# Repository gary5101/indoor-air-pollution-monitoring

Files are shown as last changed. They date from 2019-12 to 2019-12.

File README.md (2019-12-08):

Motivation
==========

Food production areas are prone to much air pollution as they will be using inflammable fuels,burning coal and other organic matter.
Despite this pollution, these areas should be kept clear of other air pollutants and gases.

Overview
========

In this project we monitor the air pollutants(Particulates,Volatile Organic Compounds,Carbon monoxide,Nitrogen dioxide,Ammonia,Methane,Propane etc) in food production areas.

The data which is collected is then sent to cloud for easy monitoring and analytics.

Here we basically collect the amount of pollutants and check the levels to assure the safety of the workers and the standards of the food.

Importance
==========

<span>Need of our Project</span>

**AQI**

The AQI is an index for reporting daily air quality. It tells you how clean or polluted your air is, and what associated health effects might be a concern for you. EPA calculates the AQI for five major air pollutants regulated by the Clean Air Act: ground-level ozone, particle pollution (also known as particulate matter), carbon monoxide, sulfur dioxide, and nitrogen dioxide. EPA has established national air quality standards to protect public health .
We use our collected data and make a AQI value and compare to the above standards to ensure a healthy environment.

<span>AQI</span> The higher the AQI value, the greater the level of air pollution and the greater the health concern.
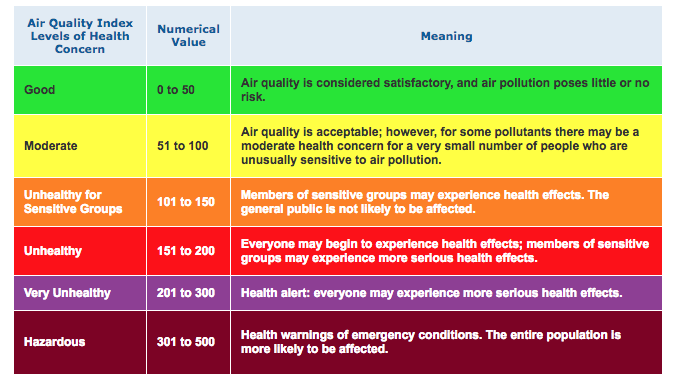
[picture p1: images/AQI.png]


Description
===========

<span>Goals</span> 

**Goals**

-   Measure the air quality index in the messes

-   To upload the air quality index to the cloud regularly to ensure the safety levels are not crossed.

-   To analyze the data collected and provide a solution if the safety levels are breached

<span>Implementation</span> 

**Steps**

-   Making the layout of the circuit

-   Connecting the sensors and controller according to the circuit

-   Writing of the code to test the sensors

-   Building of a datbase in a cloud to store the data collected

-   Update the code to connect the microcontroller to the cloud

-   Designing the final structure of the node

-   Deployment of the device

-   Analyzing the data stored in the cloud

<span>Deployment</span>

At the time of deployment of the, each node contains:-

1.  All the sensors with board(enclosed)

2.  jio-fi

3.  powerbank(power supply)

In the end 4 such node are deployed i.e 2 node in each mess

-   NBH mess

-   North mess

<span>List of Sensors and Controllers</span>

-   NodeMCU

-   Nova PM2.5 - PM10 - High Precision Air Particulate Matter Sensor

-   Digital Temperature and Humidity Sensor

-   Grove multichannel gas sensor

-   Grove - VOC and eCO2 Gas Sensor

Tools and Technologies
======================

NodeMCU
=======

<span>NodeMCU</span>

NodeMCU is an open source LUA based firmware developed for ESP8266 wifi chip.The ESP8266 is a low-cost Wi-Fi chip developed by Espressif Systems with TCP/IP protocol. NodeMCU Dev Kit has Arduino like Analog (i.e. A0) and Digital (D0-D8) pins on its board.It supports serial communication protocols i.e. UART, SPI, I2C etc.

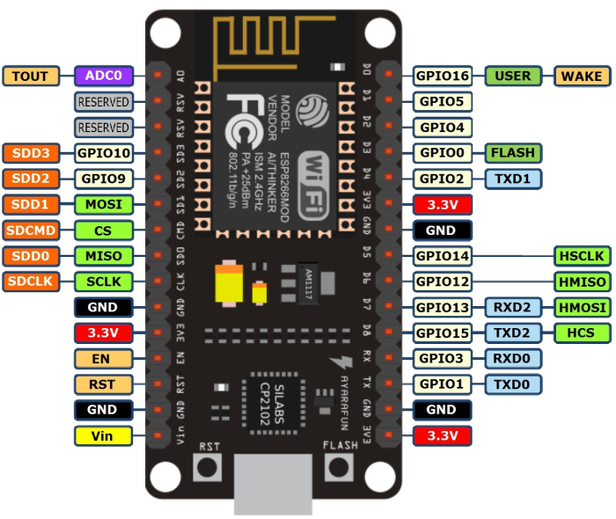
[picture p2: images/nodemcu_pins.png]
NodeMCU pin layout


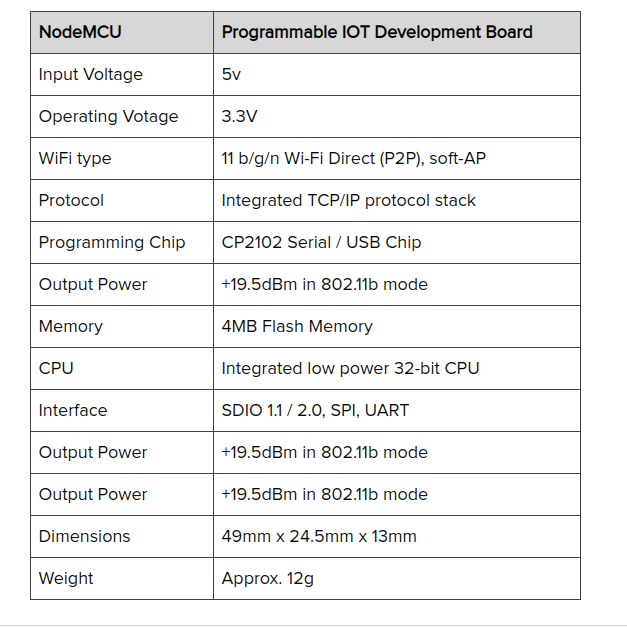
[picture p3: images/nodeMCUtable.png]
<span>NodeMCU Specifications</span> 

<span>NodeMCU vs esp32</span> ESP32 is more expensive than the ESP8266.Additionally, because it is more recent than the ESP8266, not all software has been developed to take the most out of the ESP32 functionalities, there is less support, and more bugs. But on the long run these issues will be fixed, and there will be space for both boards.

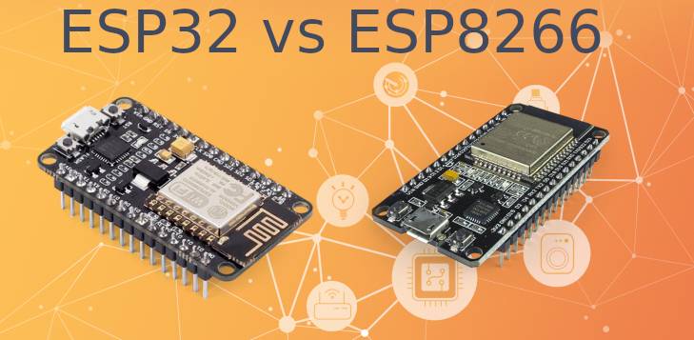
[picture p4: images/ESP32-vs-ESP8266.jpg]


Nova PM2.5 - PM10 (SDS011)
==========================

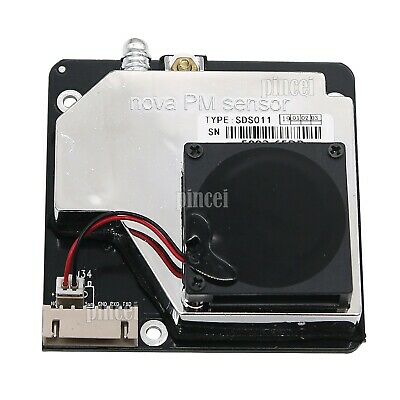
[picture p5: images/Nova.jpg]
<span>Nova PM2.5 - PM10 (SDS011)</span> The SDS011 using principle of laser scattering,can get the particle concentration between 0.3 to 10μm in the air. It gives direct digital output via serial protocol at 9600bps and also over 2 PWM channels. There is a built-in fan for stable and reliable operations. 

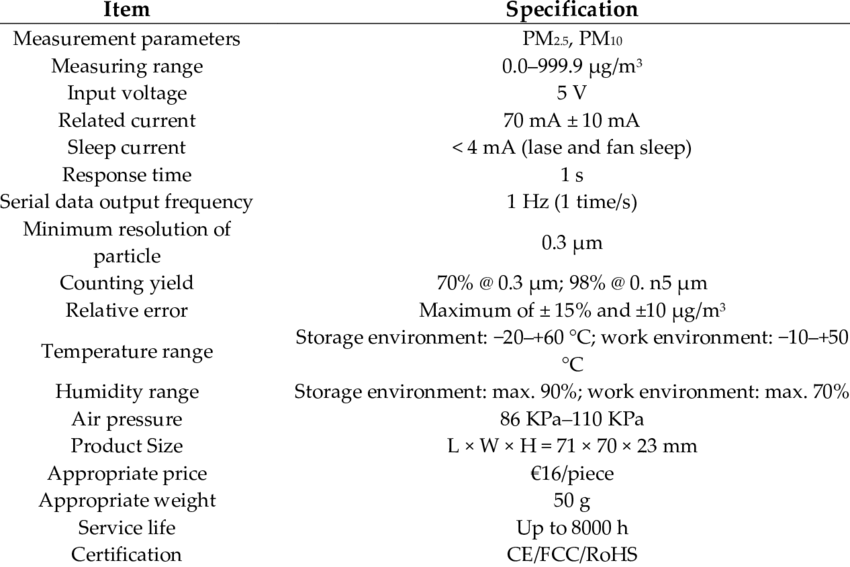
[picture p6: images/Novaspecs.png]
<span>Nova PM2.5 - PM10 (SDS011) Specifications</span> 

<span>Nova PM2.5 - PM10 (SDS011) Pin Layout</span>

-   Pin 1 - not connected

-   Pin 2 - PM2.5: 0-999μg/m³; PWM output

-   Pin 3 - 5V

-   Pin 4 - PM10: 0-999 μg/m³; PWM output

-   Pin 5 - GND

-   Pin 6 - RX UART (TTL) 3.3V

-   Pin 7 - TX UART (TTL) 3.3V

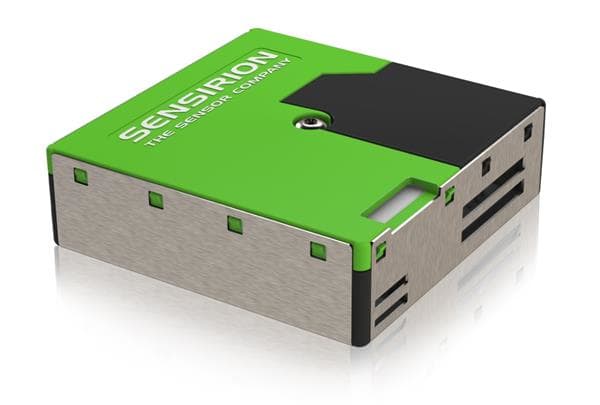
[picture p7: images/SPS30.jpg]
<span>SDS011 vs SPS30</span> 
SPS30 has sophisticated technology with high quality and long-lasting compounds which is used mostly for accurate measurements and which also makes it very expensive.For household environments SDS011 provides ease than SPS30.

DHT22 AM2302 Module
===================

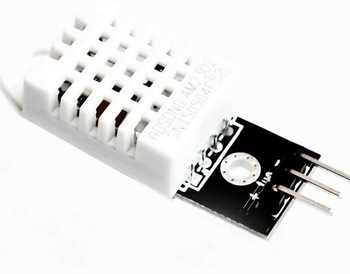
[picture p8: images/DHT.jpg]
<span>DHT22 AM2302 Module</span> It uses a capacitive humidity sensor and a thermistor to measure the surrounding air, and spits out a digital signal on the data pin (no analog input pins needed). Its fairly simple to use, but requires careful timing to grab data. The only real downside of this sensor is you can only get new data from it once every 2 seconds, so when using our library, sensor readings can be up to 2 seconds old. 

<span>DHT22 AM2302 Module Specifications</span>

-   Low cost

-   3 to 5V power and I/O

-   2.5mA max current use during conversion (while requesting data)

-   Good for 0-100

-   Good for -40 to 80$^circ$C temperature readings 0.5$^circ$C accuracy

-   No more than 0.5 Hz sampling rate (once every 2 seconds)

-   Body size 15.1mm x 25mm x 7.7mm

-   4 pins with 0.1" spacing

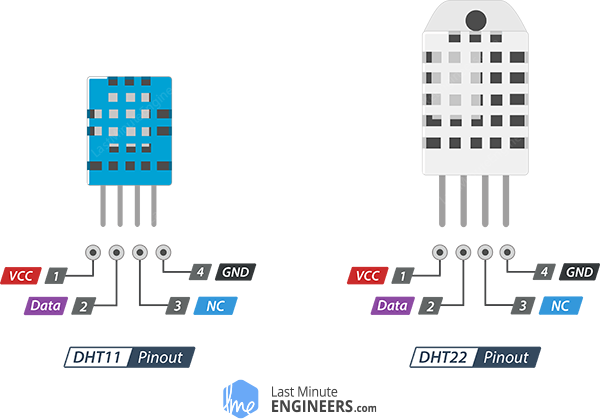
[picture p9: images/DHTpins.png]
<span>DHT22 AM2302 Pin Layout</span> 

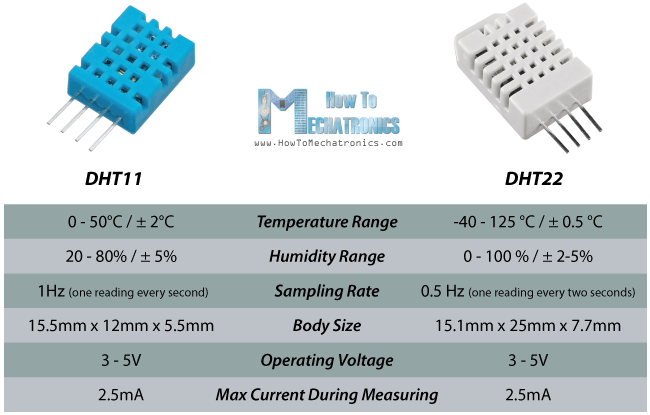
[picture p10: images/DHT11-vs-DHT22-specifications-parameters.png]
<span>DHT22 vs DHT11</span> The DHT22 is the more expensive version which obviously has better specifications. Its temperature measuring range is from -40 to +125 degrees Celsius with +-0.5 degrees accuracy, while the DHT11 temperature range is from 0 to 50 degrees Celsius with +-2 degrees accuracy. Also the DHT22 sensor has better humidity measuring range, from 0 to 100% with 2-5% accuracy, while the DHT11 humidity range is from 20 to 80% with 5% accuracy. 

Grove multichannel gas sensor
=============================

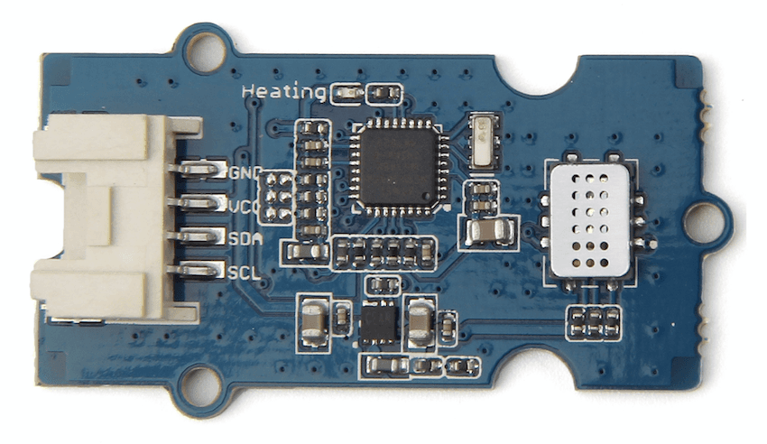
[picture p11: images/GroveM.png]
<span>Grove multichannel gas sensor</span> Grove Multichannel Gas sensor is a environment detecting sensor with a built in MiCS-6814 which can detect many unhealthful gases, and three gases can be measured simultaneously due to its multi channels, so it can help you to monitor the concentration which more than one gas. 

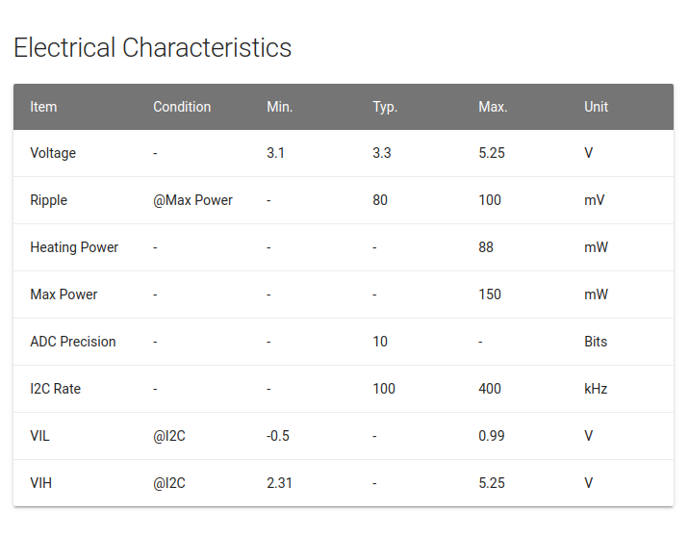
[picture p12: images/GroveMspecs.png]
<span>Grove multichannel gas sensor (MICS 6814) Characteristics</span> 

<span>Grove multichannel gas sensor (MICS 6814) Specifications</span> **Features**

-   Three fully independent sensing elements on one package

-   Built with ATmega168PA

-   I2C interface with programmable address

-   Heating power can be shut down for low power

-   Detectable gases

-   Carbon monoxide CO 1 to 1000ppm

-   Nitrogen dioxide NO2 0.05 to 10ppm

-   Ethanol C2H6OH 10 to 500ppm

-   Hydrogen H2 1 to 1000ppm

-   Ammonia NH3 1 to 500ppm

-   Methane CH4 >1000ppm

-   Propane C3H8 >1000ppm

-   Iso-butane C4H10 >1000ppm

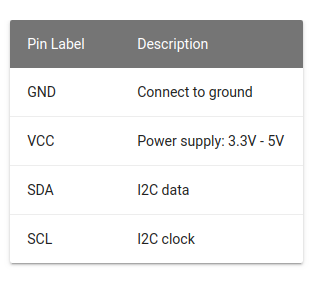
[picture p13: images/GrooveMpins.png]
<span>Grove multichannel gas sensor (MICS 6814) Pin Layout</span> 

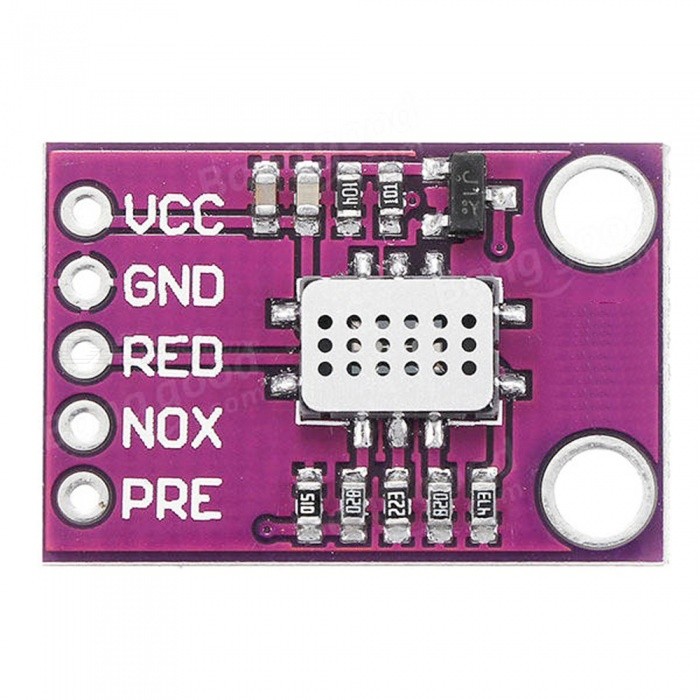
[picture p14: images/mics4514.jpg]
<span>MICS 6814 vs MICS 4514</span> 
MICS 4514 has CO/NO2 dual sensor whereas MICS 6814 has CO/NO2/NH3 triple sensor. The CO and NO2 measurements are taken by means of the MiCS-4514 MicroElectroMechanical Sensor (MEMS) [30]. This is a sensor typically used in automotive applications (e.g., to measure emissions from automobile exhausts). Hence, it is optimized for high concentration of gases,but in human environment where we don’t have such high concentrations, MICS 6814 works efficiently.

Grove - VOC and eCO2 Gas Sensor(SGP30)
======================================

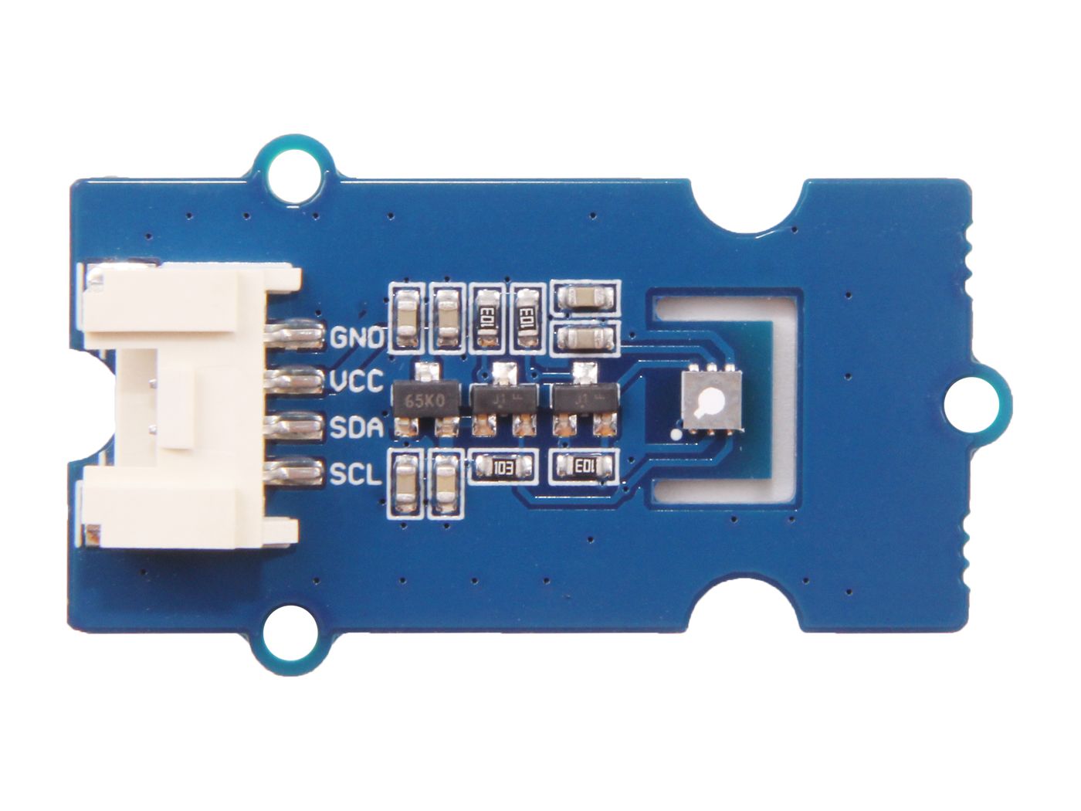
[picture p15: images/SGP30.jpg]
<span>Grove - VOC and eCO2 Gas Sensor(SGP30)</span> The Grove-VOC and eCO2 Gas Sensor(SGP30) is an air quality detection sensor. This grove module is based on SGP30, provided TVOC(Total Volatile Organic Compounds) and CO2eq output for this module. 

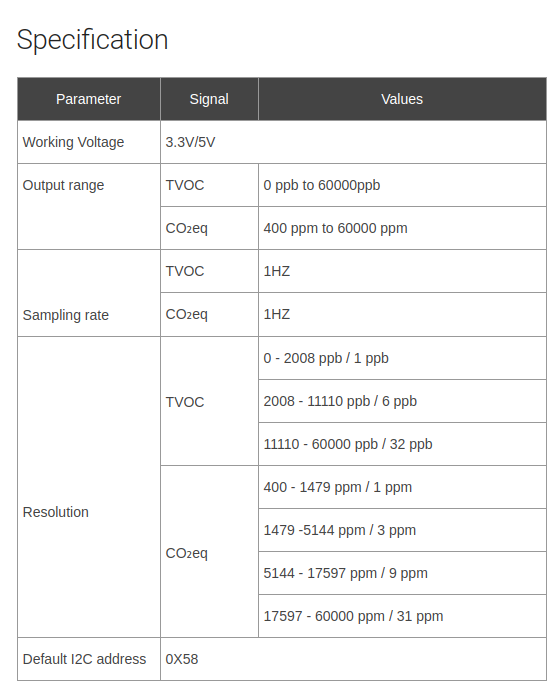
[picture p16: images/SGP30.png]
<span>Grove - VOC and eCO2 Gas Sensor(SGP30) Specifications</span> 

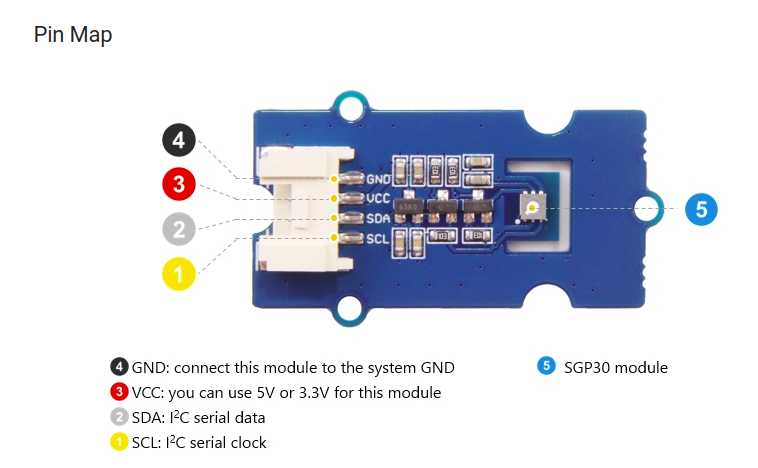
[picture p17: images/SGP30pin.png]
<span>SGP30 Pin Layout</span> 

<span>SGP30 vs CCS811</span> 

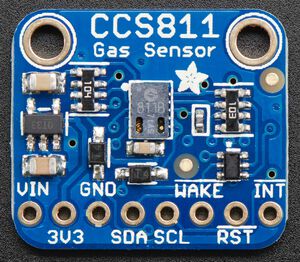
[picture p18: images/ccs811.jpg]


From a firmware perspective SGP30 is almost as easy as the CCS811. From the test data, SGP30 is way more sensitive than the CCS811. If you are in an environment where you need to know SGP30 is the one to pick. SGP30 is widely available though many channels.

Technology
==========

<span>Technology</span> **Connecting to Cloud**
The program connects to the Wi-Fi network using the provided password and SSID. It then proceeds to connect to the provided cloud/host server , and sends the provided URI to the host server.
Once the data has been successfully sent, the sketch waits for a reply from the server. The process is repeated until the ESP8266 is turned off.

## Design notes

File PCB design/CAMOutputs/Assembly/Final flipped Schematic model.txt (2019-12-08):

Partlist exported from C:/Users/VINAY KUMAR/Documents/EAGLE/projects/esw/Final flipped Schematic model.sch at 08-11-2019 11:04

Qty Value  Device                      Package Parts    Description POPULARITY VALUE 
2          PINHD-1X15                  1X15    JP1, JP2 PIN HEADER  4                
1          PINHD-1X3                   1X03    JP3      PIN HEADER  92               
1          PINHD-1X4                   1X04    JP4      PIN HEADER  91               
2   4P-2.0 GROVE-CONNECTOR-DIP(4P-2.0) HW4-2.0 J1, J2   320110033              4P-2.0

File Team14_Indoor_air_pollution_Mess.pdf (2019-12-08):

# Project Documentation

# Indoor Air Monitoring System Embedded Systems Workshop 2019

# Abhishek Reddy G Vinay Kumar T Sachin Kumar D

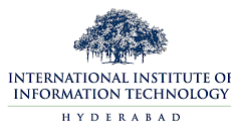
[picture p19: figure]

# International Institute of Information Technology Hyderabad

# Supervisor: Dr.Sachin Chaudhari Tanmai Mukku

# Contents

### 1 Developer Document

1.1 Introduction |
1.1.1 | Problem Definition |
1.1.2 | Purpose of System |
1.1.3 | Overview of System |
1.2 System Requirements |
1.2.1 | Hardware Requirements |
1.2.2 | Software Requirements |
1.3 System Requirements |
1.3.1 | Hardware Part |
1.3.2 | Software Part |
1.4 Stake Holders |
1.5 Design Details |
1.5.1 | Conceptual Flow |
1.5.2 | Entity Interaction |
1.6 Operational Requirements |
1.6.1 | System Needs |
1.6.2 | UI design |
1.6.3 | Analytical System |
1.7 Acknowledgement |
1.8 References |

### 2 User Document

2.1 Introduction |
2.1.1 | Objective |
2.1.2 | Scope |
2.2 Product Operational Requirements |
2.2.1 Operating Environment |
2.3 System Working Model |
2.3.1 | Base State |
2.3.2 | Working State |
2.4 Acknowledgement |

### 3 IOT Project Components

3.1 Hardware Specifications |
3.2 Communication |
3.3 Software specifications |
3.4 Data References |
3.5 Data Handling/Visualization |

# Indoor Air Quality Monitoring System

Abhishek Redddy G
Computer Science Engineering IIIT,Hyderbad,India 500032 abhishek.gangapuram@students.iiit.ac.in

Vinay Kumar T
Computer Science Engineering IIIT,Hyderbad,India 500032 vinay.kumar@students.iiit.ac.in

Sachin Kumar D
Computer Science Engineering IIIT,Hyderbad,India 500032 sachin.danisetty@students.iiit.ac.in

Dr.Sachin Chaudhari
Internet of Things
IIIT,Hyderbad,India 500032 sachin.c@iiit.ac.in

Tanmai Mukku
Computer Science Engineering IIIT,Hyderbad,India 500032 tanmai.mukku@students.iiit.ac.in

Abstract—Indoor air pollution due to household cooking is a hidden public health problem especially in developing countries. Cooking practices have an influence on the amount of pollution. Higher prevalence of respiratory infections is associated with cooking smoke especially among children. Most documented literature points toward a higher prevalence of respiratory symptoms, lung cancer and impaired lung functions with cooking smoke. Cleaner fuels seemingly cause less pollution though the literature is rare on kerosene. Identifying household air pollutants and their health implications helps us prepare for various healthrelated issues. However, the real challenge is adopting changes to reduce the health effects of household air pollution and designing innovative interventions to minimize the risk of further exposure. We present you a sophisticated model of air quality monitoring system which sense the presence of different of various air pollutants and send them to cloud for easy analysis.
Index Terms—Air Monitoring System,Kitchen,Air Pollution,Pollutants
I. INTRODUCTION

In the words of Rosalynn Carter, “There is nothing more important than a good, safe and secure home”. It is believed that a house is the most secure and healthy environment for any individual. However, the house can also be a source of various air pollutants that can have a significant adverse impact on health.
Indoor air pollution within households is one of the main contributors of mortality and disability globally. Emission due to household cooking fuels is found to be one of the main factors affecting indoor air pollution. In most parts of the developing world, traditional devices are used for cooking. The incomplete com bustion of these give rise to many pollutants including carbon monoxide, aldehydes, nitrogen oxides, polycyclic aromatic hydrocarbons, etc. . Indoor cooking is also a primary source of particle pollution, which is also called ‘particulate matter’ (PM). This consists of solid and liquid particles in the air . In a study on PM, it was found that 29-48% of source- wise attribution was from solid fuels . An Indian study revealed that 50-80% of the total suspended particulate emissions of cooking stoves using biomass and coal, were respirable being less than 2 µm in size. According to a Chinese study, PM levels during winter were significantly correlated with the usage of solid fuel. Incomplete combustion is influenced by poor ventilation and the poor quality of cooking devices used in lower-income countries . Improved cooking devices are associated with less pollution. Furthermore, factors such as higher education is associated with the usage of improved cooking devices than traditional ones . In return, negative respiratory effects are less when improved cooking devices are used .
A. Problem Definition
Monitor the Air Quality Standards in Kitchens.
Using the NodeMCU and air pollutants sensors like Particulate sensors, Humidity and Temperature sensor,Multi-channel gas sensors and VOC and CO2 sensors, collect the amount of various air pollutants and send them to ONEM2M server and IOT cloud for easy further analysis.
B. Purpose of System
Food production area are prone much air pollution as they will be using
- Inflammable fuels
- Burning coal
- Organic matter
Despite this pollution these areas should be kept clear of other air pollutants and gases. The air pollutants’s concentration should be monitored to ensure the safety of the workers and the quality of the food.
C. Overview of System
In this project we monitor the air pollutants and standards such as
•Particulates
•Volatile organic compounds
•Carbon dioxide
•Nitrogen dioxide
•Ammonia
•Carbon monoxide
•Temperature and Humidity
The data which is collected is then sent to the ONEM2M server and Thingspeak cloud for easy monitoring and analytic.

II. SYSTEM REQUIREMENTS

A. Hardware Requirements
•Should use a processing unit to collect data from different sensors.
•Sensors should be used to collect the following data. •Temperature and Humidity.
•Concentration of Particulates.
•Concentration of Volatile Organic Compounds in air. •Concentration of gases like CO2,NO,CO,NH3
•Use a portable WiFi router to connect to the Internet.
•Use a power bank to act as an uninterruptible power supply.
B. Software Requirements
•Processing unit should be capable of sending data using WiFi to a cloud software.
•Should use ONEM2M as a service layer and send data to ONEM2M servers.
•Should send data to IOT platform like Thingspeak for easy analytic.

III. SYSTEM SPECIFICATIONS

A. Hardware part
List of controllers,sensors and other devices:
- NodeMCU
We use NodeMCU as our central processing unit connecting air pollutants sensors
– NodeMCU is an open source LUA based firmware developed for ESP8266 wifi chip.
– The ESP8266 is a low-cost Wi-Fi chip developed by Espressif Systems with TCP/IP protocol.
– NodeMCU Dev Kit has Arduino like Analog (i.e. A0) and Digital (D0-D8) pins on its board.
– It supports serial communication protocols i.e. UART, SPI, I2C etc.
- Nova PM2.5-PM10 Particulate Sensor(SDS011)
We use Nova particulate sensor to sense particulates with size under 2.5nm and more than 10nm in diameter.
– The SDS011 using principle of laser scattering,can get the particle concentration between 0.3 to 10µm in the air.
– It gives direct digital output via serial protocol at 9600bps and also over 2 PWM channels.
– There is a built-in fan for stable and reliable operations.
- Digital Humidity and Temperature Sensor(DHT22)

– It uses a capacitive humidity sensor and a thermistor to measure the surrounding air, and spits out a digital signal on the data pin (no analog input pins needed). – Its fairly simple to use, but requires careful timing to grab data.


Fig. 1. NodeMCU specifications [1]


Fig. 2. Nova PM2.5-PM10 sensor specifications [2]

– The only real downside of this sensor is you can only get new data from it once every 2 seconds, so when using our library, sensor readings can be up to 2 seconds old.
– DHT22 specifications [3]:
∗ Low cost
∗ 3 to 5V power and I/O
∗ 2.5mA max current use during conversion (while requesting data)
∗ Good for 0-100
∗ Good for -40 to 80 ◦ C temperature readings 0.5
- C accuracy
∗ No more than 0.5 Hz sampling rate (once every 2 seconds)
∗ Body size 15.1mm x 25mm x 7.7mm
- Grove Multi-channel sensor(MiCS-6814)
– Grove Multi-channel Gas sensor is a environment detecting sensor with a built in MiCS-6814 which can detect many unhealthful gases, and three gases can be measured simultaneously due to its multi channels,


Fig. 3. SGP-30 specifications [5]

so it can help you to monitor the concentration which more than one gas.
– Multi-channel gas sensor specifications [4]:

∗ Three fully independent sensing elements on one package
∗ Built with ATmega168PA
∗ I2C interface with programmable address
∗ Heating power can be shut down for low power ∗ Detectable gases
∗ Carbon monoxide CO 1 to 1000ppm
∗ Nitrogen dioxide NO2 0.05 to 10ppm
∗ Ethanol C2H6OH 10 to 500ppm
∗ Hydrogen H2 1 to 1000ppm
∗ Ammonia NH3 1 to 500ppm
∗ Methane CH4 ¿1000ppm
∗ Propane C3H8 ¿1000ppm
∗ Iso-butane C4H10 ¿1000ppm
- Grove VOC and CO2 Gas sensor(SGP-30)
– The Grove-VOC and eCO2 Gas Sensor(SGP30) is an air quality detection sensor.
– This grove module is based on SGP30, provided TVOC(Total Volatile Organic Compounds) and CO2eq output for this module.
- JioFi(JMR1040)
– We use JioFi to get internet access to post the data obtained from sensors in an ONEM2M server and IOT cloud to store them and for easy further analysis
- Zinq power bank
– We use a power bank to provide an uninterruptible power service for the whole device.

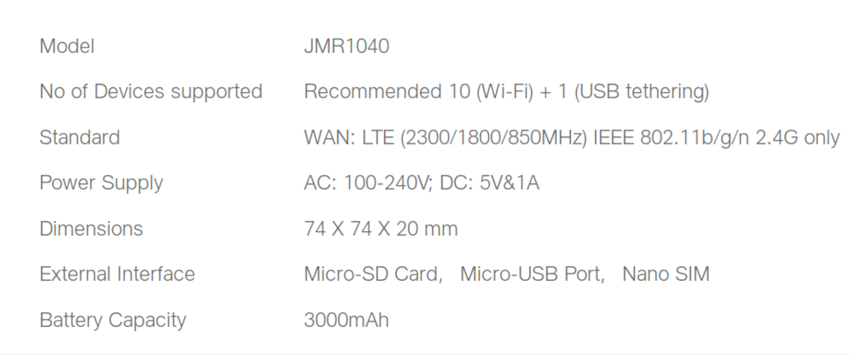
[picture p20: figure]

Fig. 4. JioFi specifications [6]

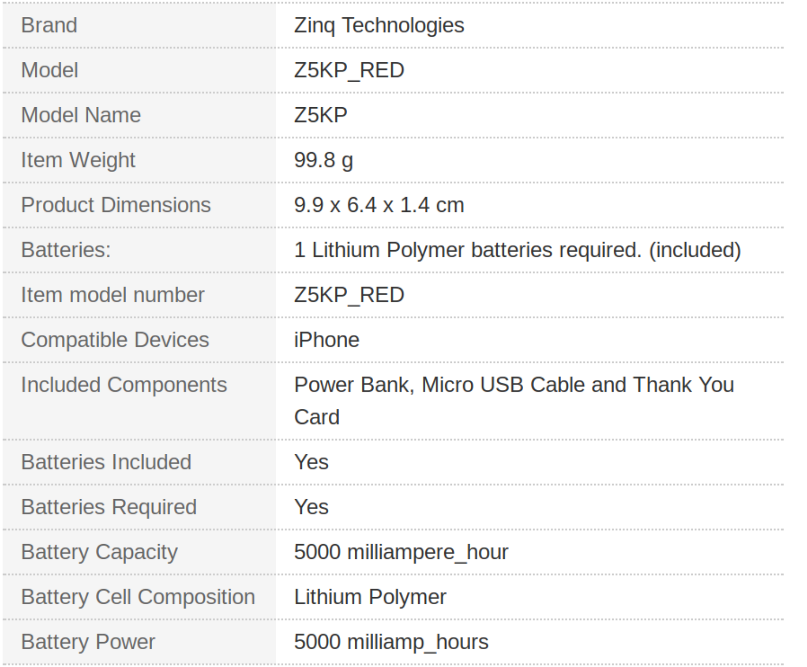
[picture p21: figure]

Fig. 5. Zinq power bank specifications [7]

– Ultra small and powerful: Smallest size for its capacity of 5000 mAh is very portable and easy to carry
– Input-output versatility: The power bank has Single input charging options of micro USB and has dual output ports with 2.0A fast charging
– 6-level protection: Built using the highest quality Lipolymer battery and protection from short circuits, current and voltage overloads overheating and wrong insertion
– Led indicator: A led indicators to find the status of charge ensuring you exactly know so that you don’t run into surprises
– Compatibility: Charge your iPhone, all Android devices, tablets, cameras and iPod, headphones
B. Software part
1) Arduino: We use Arduino IDE [8] for flashing the code in NodeMCU.Code is mentioned in the github repository given at last.
Arduino is an open-source physical computing platform based on a simple I/O board and a development environment that implements the Processing/Wiring language. Arduino can be used to develop stand-alone interactive objects or can be connected to software on your computer (e.g. Flash, Processing and MaxMSP). The boards can be assembled by hand or purchased preassembled; the open-source IDE can be downloaded for free at https://arduino.cc
2) ONEM2M: We added ONEM2M [9] service layer to our model to make it easy for machine to machine communication and security. We use ONEM2M API to send data to ONEM2M server.
The purpose and goal of oneM2M is to develop technical specifications which address the need for a common M2M Service Layer that can be readily embedded within various hardware and software, and relied upon to connect the myriad of devices in the field with M2M application servers worldwide. A critical objective of oneM2M is to attract and actively involve organizations from M2M-related business domains such as: telematics and intelligent transportation, healthcare, utilities, industrial automation, smart homes, etc.
3) Thingspeak: We also use Thingspeak [10] for IOT cloud to store data and do further analytic with MATLAB(integrated with Thingspeak).
our MATLAB functions used to analyze the air quality data collected by ThingSpeak. The MATLAB code helps preprocess the sensor data, provides functions to classify the data, and provides functions for visualizing the processed air quality data. The MATLAB visualizations are added to a ThingSpeak channel dashboard so you can see the current air quality near you. The MATLAB analysis code calculates the AQI using the definitions from the United States Environmental Protection Agency (EPA).
4) Dashboard: We built a data analysis dashboard on ThingSpeak using our available data and MATLAB. This project it makes it easy to explore IoT data analysis using MATLAB to preprocess and visualize data without having IoT hardware.

IV. STAKE HOLDERS

This device affects all the people working in mess or kitchens. It also affects the food quality.

V. DESIGN DETAILS
A. Conceptual Flow
The working of the device go as follows
- Firstly the processing unit,NodeMCU take power from the power bank and run the code flashed into it.
- NodeMCU, using its esp8266 WiFi module connects to the JioFi through the given SSID and password.
- Now NodeMCU collects data from each sensor and store them in variables.The NodeMCU collects data every 30 seconds.
- The data stored in variables is sent to different Thingspeak channels by using thingspeak API in Arduino IDE.
- For every 15 minutes, The NodeMCU post recent data to ONEM2M server by a certain CSE IP ,here it is onem2m.iiit.ac.in with port 80.
B. Entity Interaction
We have entities interacting in many different ways.
- NodeMCU - SDS011
This interaction uses UART communication.Rx pin of NodeMCU is connected to Tx pin of SDS011 and Tx pin of NodeMCU is connected to Rx pin of SDS011.

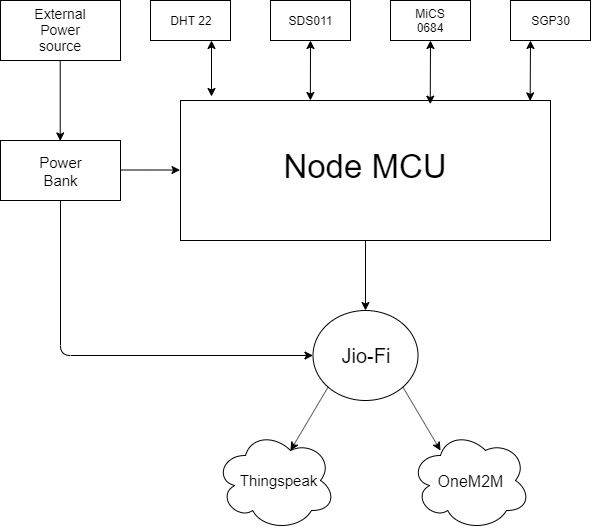
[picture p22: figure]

Fig. 6. Block diagram representation of the flow

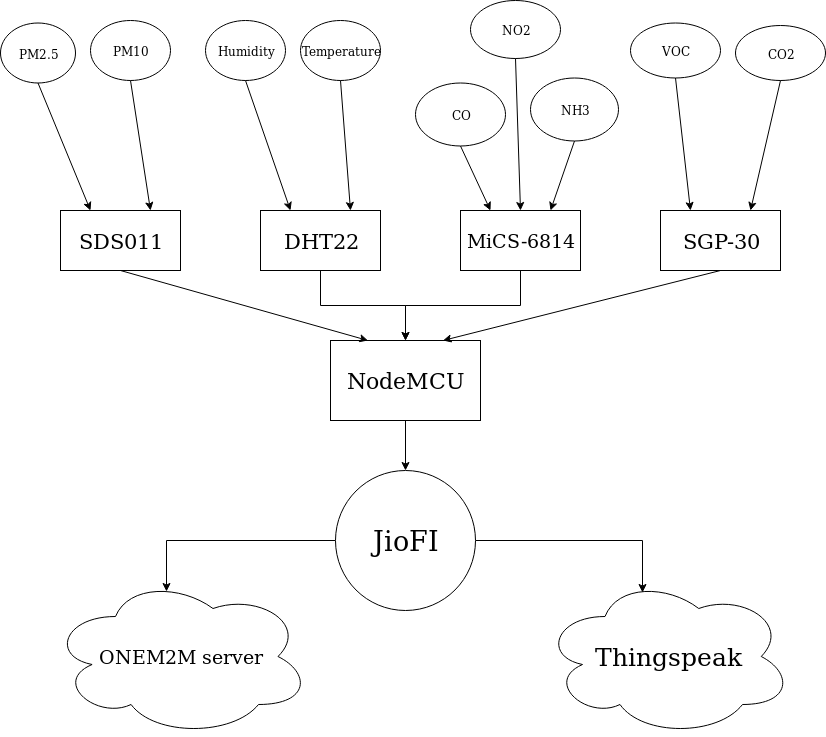
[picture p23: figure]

Fig. 7. Entities Interacting

- NodeMCU - DHT22
This interaction uses GPIO communication.D3 pin of NodeMCU is connected to DHT22.
- NodeMCU - MiCS-6814
This interaction uses I2C communication.D0 and D1 pins of NodeMCU are connected to SCK and SDA pins of Mics-6814.
- NodeMCU - SGP-30
This interaction uses I2C communication.D0 and D1 pins of NodeMCU are connected to SCK and SDA pins of SGP-30.
- NodeMCU - JioFi
This interaction uses WiFi communication.NodeMCU uses esp 8266 module to communicate to JioFi through WiFi.
- JioFi - ONEM2M or Thingspeak
Here the data is sent through post requests to both the servers and is stored there.

VI. OPERATIONAL REQUIREMENTS

A. System Needs
- Although power bank serves as the uninterruptible power source for both NodeMCU and JioFi,Power bank should be connected to a power source like a power socket all the time even when power bank is fully charged.
- The device should be hanged in open space in kitchen.It should be at a suitable height to get affected by pollutants.
- Since we need internet to post data to cloud, we need of consistent network signal for JioFi in the kitchen.
B. UI design
The device is cleanly,compactly enclosed in 3D-enclosure with two sides with grid walls to let free passage of air.
We can check the working condition by the led lights provided by JioFi to verify whether NodeMCU is connected to it or not. The power source can be verified by checking the led lights on power bank.
C. Analytical System
- ThingSpeak support functions let you use desktop MAT-LAB to analyze and visualize data stored on ThingSpeak.com or on private installations of ThingSpeak. With the MATLAB engine built into ThingSpeak, you can perform calibrations, develop analytics, and transform your IoT data.
Operationalize your analytics using the Time Control and React apps. With the Time Control app, you can schedule a computation to run once a day, once an hour, or as quickly as once every 5 minutes. The React App is used for condition monitoring. You can monitor the data coming in from your devices and set up an alert when the data indicates something may need attention.
- The data in ONEM2M server is stored in containers with time stamps,So, We know the date and time when the air pollutant levels are breached.

ACKNOWLEDGMENT
The work described in this project was conducted within IIIT Hyderabad and also funded by IIIT Hyderabad under Embedded Systems Workshop 2019.We sincerely thank Dr.Sachin Chaudhari and Tanmai Mukku for their support and guidance through the whole project.

REFERENCES

[1] https://veerobot.com/store/CB-MCU-IOTB-12
[2] https://cdn-reichelt.de/documents/datenblatt/X200/SDS011-DATASHEET.pdf
[3] https://www.adafruit.com/product/385
[4] http://wiki.seeedstudio.com/Grove-Multichannel Gas Sensor/
[5] http://wiki.seeedstudio.com/Grove-VOC and eCO2 Gas Sensor-SGP30/
[6] https://www.jio.com/shop/en-in/router-jmr1040-white/p/491193523
[7] https://www.amazon.in/Zinq-Technologies-Z10KI-10000mAH-Lithium/dp/B07MHCFRW5
[8] https://www.arduino.cc/en/main/software
[9] http://www.onem2m.org/about-onem2m/why-onem2m
[10] https://thingspeak.com/

# User Document

Abstract—We present you a sophisticated model of air quality monitoring system which sense the presence of different of various air pollutants and send them to cloud for easy analysis. Index Terms—Air Monitoring System,Kitchen,Air Pollution,Pollutants

I. INTRODUCTION

Indoor air pollution within households is one of the main contributors of mortality and disability globally. Emission due to household cooking fuels is found to be one of the main factors affecting indoor air pollution. In most parts of the developing world, traditional devices are used for cooking. The incomplete com bustion of these give rise to many pollutants including carbon monoxide, aldehydes, nitrogen oxides, polycyclic aromatic hydrocarbons, etc. . Indoor cooking is also a primary source of particle pollution, which is also called ‘particulate matter’ (PM). This consists of solid and liquid particles in the air . In a study on PM, it was found that 29-48% of source- wise attribution was from solid fuels

A. Objective
Monitor the Air Quality Standards in Kitchens.
With this device we should monitor the air pollutants and standards such as
•Particulates
•Volatile organic compounds
•Carbon dioxide
•Nitrogen dioxide
•Ammonia
•Carbon monoxide
•Temperature and Humidity
The data which is collected is then sent to the ONEM2M server and Thingspeak cloud for easy monitoring and analytic.
B. Scope
Food production area are prone much air pollution as they will be using
- Inflammable fuels
- Burning coal
- Organic matter
Despite this pollution these areas should be kept clear of other air pollutants and gases. The air pollutants’s concentration should be monitored to ensure the safety of the workers and the quality of the food.

II. PRODUCT OPERATIONAL REQUIREMENTS

A. Operating Environment
- This device is focused on but not constrained to kitchens and other food production areas.
- The device must be kept in an open space to let be affected by air pollutants.
- The device should be hanged at an appropriate height to the wall.
- The device should not get into contact with any liquid.
- The device shouldn’t kept directly above stove or below an exhaust fan.
- The device should be connected to a 220V socket.
- The device should have proper network signal to post data to cloud.
- The JioFi data card should have an active internet package to get access to internet.

III. SYSTEM WORKING MODEL
A. Base State
The first prototype is designed for testing and calibration with no physical enclosure.
It was designed on a breadboard.Then it was upgraded to a perforated circuit board.
It doesn’t include JioFi and power bank.
It has a power socket as it’s power source,since it is not an uninterruptible power source,the device is not a steady state device.
It was only integrated with Thingspeak.
Testing and Calibrating was done in a lab for a week and proper adjustments were made.
B. Working State
The working model is an advanced model of Base state. It was enclosed in a physical enclosure with some walls replaced by grills to have free passage of air.
The working state include JioFi and power bank which were absent in the Base state.
The working system has an uninterruptible power source unlike Base state.
The working state is designed on Printed Circuit Board which improve compactness to a great extent.
It is integrated with both Thingspeak and ONEM2M.The data can be accessed by ONEM2M dashboard and Thingspeak dashboard.It is even accessible in mobile through various mobile applications like Thingsview etc.

ACKNOWLEDGMENT
The work described in this project was conducted within IIIT Hyderabad and also funded by IIIT Hyderabad under Embedded Systems Workshop 2019.We sincerely thank Dr.Sachin Chaudhari and Tanmai Mukku for their support and guidance through the whole project.We also like to thank the Embedded Systems Workshop Professors for their guidance in various aspects and fields.

# 3 IOT Project Components

## 3.1 Hardware Specifications

- NodeMCU
NodeMCU is an open source LUA based firmware developed for ESP8266 wifi chip.The ESP8266 is a low-cost Wi-Fi chip developed by Espressif Systems with TCP/IP protocol. NodeMCU Dev Kit has Arduino like Analog (i.e. A0) and Digital (D0-D8) pins on its board.It supports serial communication protocols i.e. UART, SPI, I2C etc
- SDS011
The SDS011 using principle of laser scattering,can get the particle concentration between 0.3 to 10ˆIijm in the air. It gives direct digital output via serial protocol at 9600bps and also over 2 PWM channels. There is a built-in fan for stable and reliable operations
- DHT22
It uses a capacitive humidity sensor and a thermistor to measure the surrounding air, and spits out a digital signal on the data pin (no analog input pins needed). Its fairly simple to use, but requires careful timing to grab data. The only real downside of this sensor is you can only get new data from it once every 2 seconds, so when using our library, sensor readings can be up to 2 seconds old.
- MiCS-6814 Grove Multichannel Gas sensor is a environment detecting sensor with a built in MiCS-6814 which can detect many unhealthful gases, and three gases can be measured simultaneously due to its multi channels, so it can help you to monitor the concentration which more than one gas.
- SGP-30
The Grove-VOC and eCO2 Gas Sensor(SGP30) is an air quality detection sensor. This grove module is based on SGP30, provided TVOC(Total Volatile Organic Compounds) and CO2eq output for this module.

## 3.2 Communication

OneM2M is used for communication between the Node and Server. It has the following uses:

- Security and privacy aspects(authentication, encryption, integrity verification).
- Identification and naming of devices(for differentiating different devices).
- Data aggregation, buffering in case of missing connectivity and synchronisation upon connectivity re-establishment
- Group management and application and data discovery functions

Other forms of communications like UART and I2C are also used for the interacting components but are not used in the communication between the server and the node.

## 3.3 Software specifications

- Arduino IDE is used to program the microcontroller.
- Eagle Cad is used to design the printed circuit board.
- Fusion 360 is used to design the 3D printed box.
- Microsoft Excel is used to draw graphs for the collected data and for analysis.
- EasyEDA is used to draw the schematic representation of the circuit in the node.

## 3.4 Data References

Thingspeak

- https://thingspeak.com/channels/864652
- https://thingspeak.com/channels/864651
- https://thingspeak.com/channels/864650
- https://thingspeak.com/channels/864649
- https://thingspeak.com/channels/906528
- https://thingspeak.com/channels/907653
- https://thingspeak.com/channels/907654
- https://thingspeak.com/channels/907655

Github
https://github.com/SachinKumar105/Embedded-Systems-Workshop
OneM2M
http://onem2m.iiit.ac.in/webpage/welcome/index.html?context=/~&cseId=in-cse

## 3.5 Data Handling/Visualization

The data from the server is pulled by web-scraping. The data is also sent to Thingspeak server from where the data can be retrieved in an .xlsx format. The data from both are converted to the excel form and are further filtered and sorted according to date and time to provide better view of the results. These results are then represented as graphs.For Each of the sensors the average is taken for each day and for a particular day where the values are closest to these averages , the values are taken for each hour to see the change in the concentration of the gases across different times of the day. The obtained graphs for various sensors are as follows:

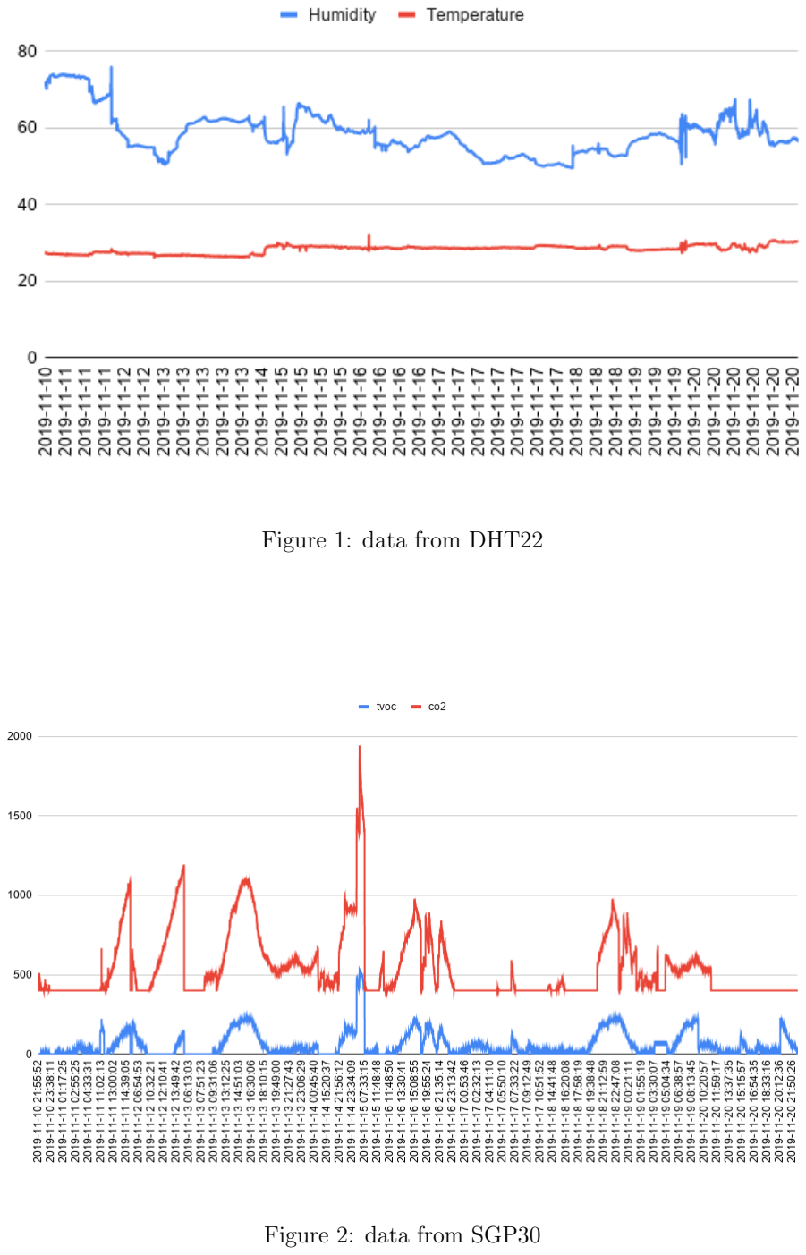
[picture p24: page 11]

Figure 1: data from DHT22

Figure 2: data from SGP30

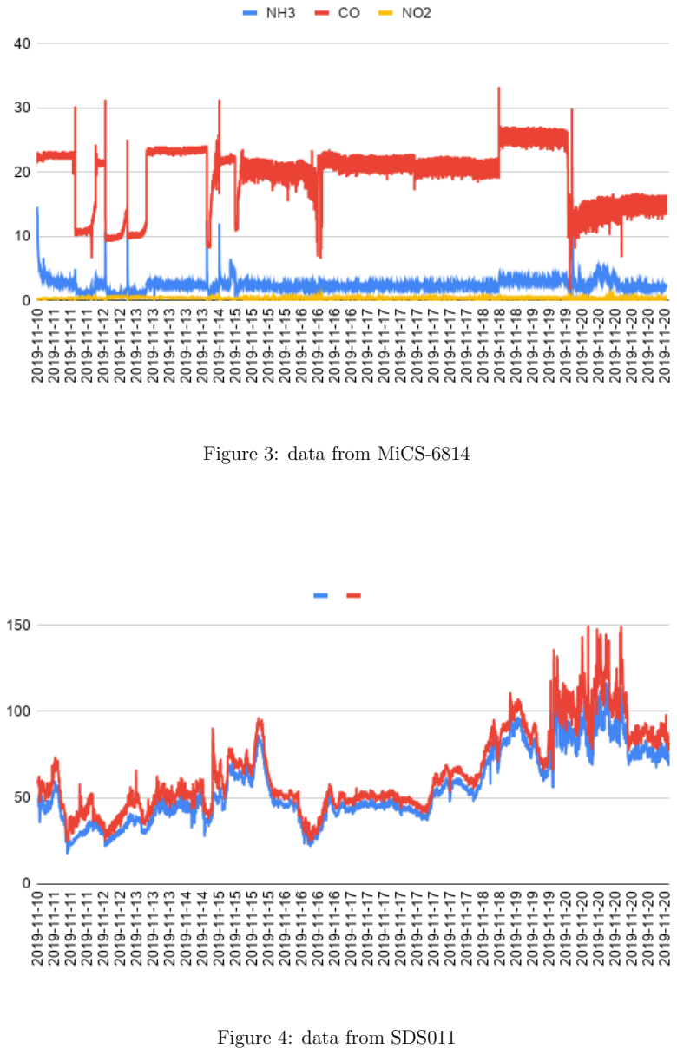
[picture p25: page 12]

Figure 3: data from MiCS-6814

Figure 4: data from SDS011

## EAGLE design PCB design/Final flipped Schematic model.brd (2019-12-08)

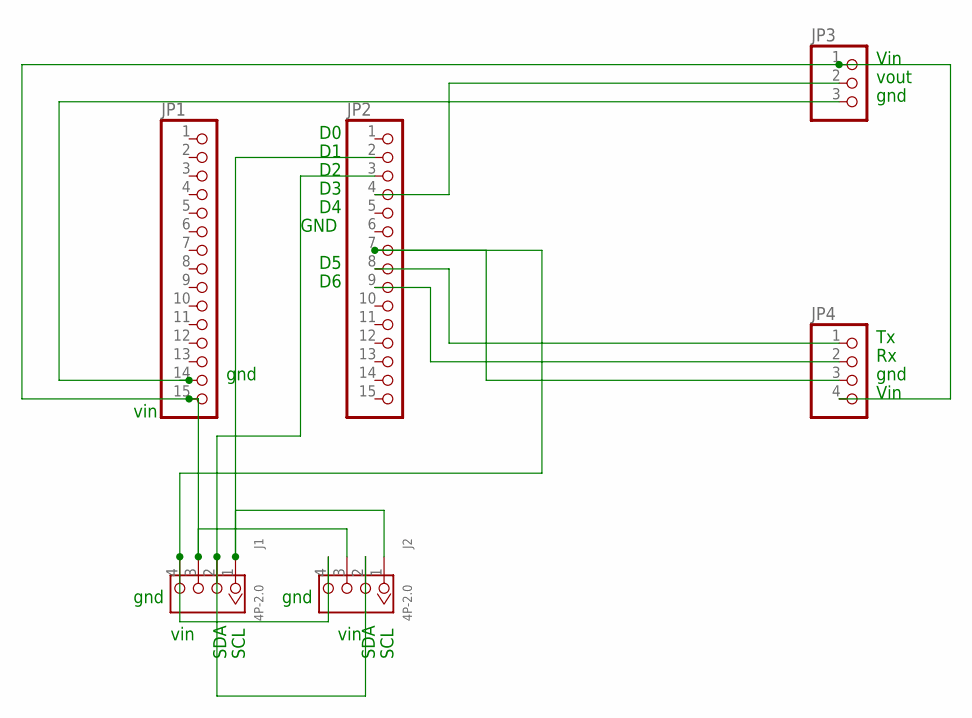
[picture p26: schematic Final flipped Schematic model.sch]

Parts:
J1, J2: 4P-2.0; HW4-2.0
JP1, JP2: PINHD-1X15; 1X15
JP3: PINHD-1X3; 1X03
JP4: PINHD-1X4; 1X04

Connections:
unnamed: JP2.8, JP4.1
unnamed: JP2.9, JP4.2
unnamed: JP2.4, JP3.2
unnamed: J1.1, J2.1, JP2.2
unnamed: J1.4, J2.4, JP2.7, JP4.3
unnamed: J1.2, J2.2, JP2.3
unnamed: J1.3, J2.3, JP1.15, JP3.1, JP4.4
unnamed: JP1.14, JP3.3

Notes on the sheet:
Vin
gnd
vout
GND
vin
SDA
SCL

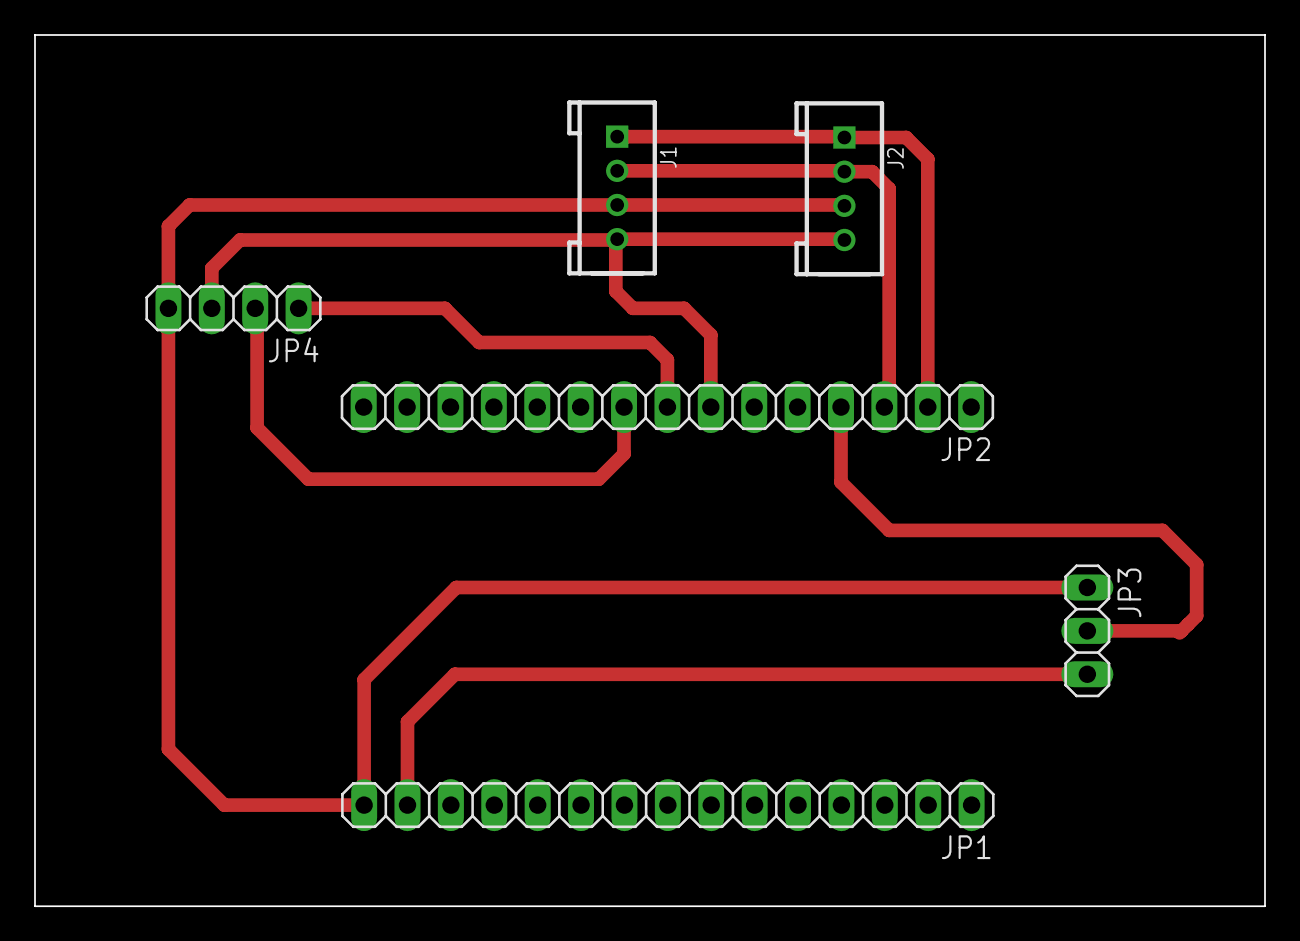
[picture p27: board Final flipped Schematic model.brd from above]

Board: 2 copper layers, 72.0 x 51.0 mm, 6 parts (0 on the bottom side), 8 nets.

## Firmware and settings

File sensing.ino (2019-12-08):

#include <JSONVar.h>
#include <Arduino_JSON.h>
#include <JSON.h>
#include <Wire.h>
#include "Adafruit_SGP30.h"
#include "MutichannelGasSensor.h"
#include <ESP8266WiFi.h>
#include <SoftwareSerial.h>
#include "SdsDustSensor.h"
#include "ThingSpeak.h"
#include <Arduino.h>
#include "sensirion_common.h"

#include <Adafruit_Sensor.h>
#include "DHT.h"
// Use this file to store all of the private credentials
// and connection details

#define SECRET_CH_ID1 864649      // replace 0000000 with your channel number
#define SECRET_WRITE_APIKEY1 "D6WO0I37GORJEIV9"   // replace XYZ with your channel write API Key

#define SECRET_CH_ID2 864650      // replace 0000000 with your channel number
#define SECRET_WRITE_APIKEY2 "DDEGP9X1V4WEGEFH"   // replace XYZ with your channel write API Key

#define SECRET_CH_ID3 864651      // replace 0000000 with your channel number
#define SECRET_WRITE_APIKEY3 "MC5M1BZI4U9422XF"   // replace XYZ with your channel write API Key

#define SECRET_CH_ID4 864652      // replace 0000000 with your channel number
#define SECRET_WRITE_APIKEY4 "1T9T3FK7NR422DJP"   // replace XYZ with your channel write API Key

//#define SECRET_CH_ID1 906528      // replace 0000000 with your channel number
//#define SECRET_WRITE_APIKEY1 "LL4J2EL6WCIW3SKD"   // replace XYZ with your channel write API Key
//
//#define SECRET_CH_ID2 907653      // replace 0000000 with your channel number
//#define SECRET_WRITE_APIKEY2 "JIT20STHHFLPYTBD"   // replace XYZ with your channel write API Key
//
//#define SECRET_CH_ID3 907654      // replace 0000000 with your channel number
//#define SECRET_WRITE_APIKEY3 "XSP8H1C1CD9VDQ2K"   // replace XYZ with your channel write API Key
//
//#define SECRET_CH_ID4 907655      // replace 0000000 with your channel number
//#define SECRET_WRITE_APIKEY4 "Z5HI2QGCMDXMTGQ0"   // replace XYZ with your channel write API Key
int rxPin = 14;
int txPin = 15;
SdsDustSensor sds(rxPin, txPin);

uint32_t delayMS;

int x;
// ##################### Update the Wifi SSID, Password and IP adress of the server ##########
// WIFI params
char* WIFI_SSID = "JioFi_20FDE31";
char* WIFI_PSWD = "n5v406hr5d";
//char* WIFI_SSID = "WPS unavailable";
//char* WIFI_PSWD = "no game no life";

String CSE_IP      = "onem2m.iiit.ac.in";
// #######################################################

int WIFI_DELAY  = 100; //ms

// oneM2M : CSE params
int   CSE_HTTP_PORT = 80;
String CSE_NAME    = "in-name";
String CSE_M2M_ORIGIN  = "admin:admin";

// oneM2M : resources' params
String DESC_CNT_NAME = "DESCRIPTOR";
String DATA_CNT_NAME = "DATA";
String CMND_CNT_NAME = "COMMAND";
int TY_AE  = 2;
int TY_CNT = 3;
int TY_CI  = 4;
int TY_SUB = 23;

// HTTP constants
int LOCAL_PORT = 9999;
char* HTTP_CREATED = "HTTP/1.1 201 Created";
char* HTTP_OK    = "HTTP/1.1 200 OK\r\n";
int REQUEST_TIME_OUT = 5000; //ms

//MISC
//int LED_PIN   = D1;/
int SERIAL_SPEED  = 9600;

#define DEBUG

///////////////////////////////////////////
//sensor variables
#define DHTPIN 0  // Digital pin connected to the DHT sensor
#define DHTTYPE DHT22   // DHT 22  (AM2302), AM2321
DHT dht(DHTPIN, DHTTYPE);
float dht_val[2];
Adafruit_SGP30 sgp;


///////////////////////////////////////////



// Global variables
WiFiServer server(LOCAL_PORT);    // HTTP Server (over WiFi). Binded to listen on LOCAL_PORT contant
WiFiClient client;
String context = "";
String command = "";        // The received command
unsigned long myChannelNumber1 = SECRET_CH_ID1;
const char * myWriteAPIKey1 = SECRET_WRITE_APIKEY1;

unsigned long myChannelNumber2 = SECRET_CH_ID2;
const char * myWriteAPIKey2 = SECRET_WRITE_APIKEY2;
unsigned long myChannelNumber3 = SECRET_CH_ID3;
const char * myWriteAPIKey3 = SECRET_WRITE_APIKEY3;
unsigned long myChannelNumber4 = SECRET_CH_ID4;
const char * myWriteAPIKey4 = SECRET_WRITE_APIKEY4;

String myStatus = "";


// Method for creating an HTTP POST with preconfigured oneM2M headers
// param : url  --> the url path of the targted oneM2M resource on the remote CSE
// param : ty --> content-type being sent over this POST request (2 for ae, 3 for cnt, etc.)
// param : rep  --> the representaton of the resource in JSON format
String doPOST(String url, int ty, String rep) {

  String postRequest = String() + "POST " + url + " HTTP/1.1\r\n" +
                       "Host: " + CSE_IP + ":" + CSE_HTTP_PORT + "\r\n" +
                       "X-M2M-Origin: " + CSE_M2M_ORIGIN + "\r\n" +
                       "Content-Type: application/json;ty=" + ty + "\r\n" +
                       "Content-Length: " + rep.length() + "\r\n"
                       "Connection: close\r\n\n" +
                       rep;

  // Connect to the CSE address

  Serial.println("connecting to " + CSE_IP + ":" + CSE_HTTP_PORT + " ...");

  // Get a client
  WiFiClient client;
  if (!client.connect(CSE_IP, CSE_HTTP_PORT)) {
    Serial.println("Connection failed !");
    return "error";
  }

  // if connection succeeds, we show the request to be send
#ifdef DEBUG
  Serial.println(postRequest);
#endif

  // Send the HTTP POST request
  client.print(postRequest);

  // Manage a timeout
  unsigned long startTime = millis();
  while (client.available() == 0) {
    if (millis() - startTime > REQUEST_TIME_OUT) {
      Serial.println("Client Timeout");
      client.stop();
      return "error";
    }
  }

  // If success, Read the HTTP response
  String result = "";
  if (client.available()) {
    result = client.readStringUntil('\r');
    //    Serial.println(result);
  }
  while (client.available()) {
    String line = client.readStringUntil('\r');
    Serial.print(line);
  }
  Serial.println();
  Serial.println("closing connection...");
  return result;
}

// Method for creating an ApplicationEntity(AE) resource on the remote CSE (this is done by sending a POST request)
// param : ae --> the AE name (should be unique under the remote CSE)
String createAE(String ae) {
  String aeRepresentation =
    "{\"m2m:ae\": {"
    "\"rn\":\"" + ae + "\","
    "\"api\":\"org.demo." + ae + "\","
    "\"rr\":\"true\","
    "\"poa\":[\"http://" + WiFi.localIP().toString() + ":" + LOCAL_PORT + "/" + ae + "\"]"
    "}}";
#ifdef DEBUG
  Serial.println(aeRepresentation);
#endif
  return doPOST("/" + CSE_NAME, TY_AE, aeRepresentation);
}

// Method for creating an Container(CNT) resource on the remote CSE under a specific AE (this is done by sending a POST request)
// param : ae --> the targeted AE name (should be unique under the remote CSE)
// param : cnt  --> the CNT name to be created under this AE (should be unique under this AE)
String createCNT(String ae, String cnt) {
  String cntRepresentation =
    "{\"m2m:cnt\": {"
    "\"rn\":\"" + cnt + "\","
    "\"min\":\"" + -1 + "\""
    "}}";
  return doPOST("/" + CSE_NAME + "/" + ae, TY_CNT, cntRepresentation);
}

// Method for creating an ContentInstance(CI) resource on the remote CSE under a specific CNT (this is done by sending a POST request)
// param : ae --> the targted AE name (should be unique under the remote CSE)
// param : cnt  --> the targeted CNT name (should be unique under this AE)
// param : ciContent --> the CI content (not the name, we don't give a name for ContentInstances)
String createCI(String ae, String cnt, String ciContent) {
  String ciRepresentation =
    "{\"m2m:cin\": {"
    "\"con\":\"" + ciContent + "\""
    "}}";
  return doPOST("/" + CSE_NAME + "/" + ae + "/" + cnt, TY_CI, ciRepresentation);
}


// Method for creating an Subscription (SUB) resource on the remote CSE (this is done by sending a POST request)
// param : ae --> The AE name under which the SUB will be created .(should be unique under the remote CSE)
//          The SUB resource will be created under the COMMAND container more precisely.
String createSUB(String ae) {
  String subRepresentation =
    "{\"m2m:sub\": {"
    "\"rn\":\"SUB_" + ae + "\","
    "\"nu\":[\"" + CSE_NAME + "/" + ae  + "\"], "
    "\"nct\":1"
    "}}";
  return doPOST("/" + CSE_NAME + "/" + ae + "/" + CMND_CNT_NAME, TY_SUB, subRepresentation);
}


// Method to register a module (i.e. sensor or actuator) on a remote oneM2M CSE
void registerModule(String module, bool isActuator, String intialDescription, String initialData) {
  if (WiFi.status() == WL_CONNECTED) {
    String result;
    // 1. Create the ApplicationEntity (AE) for this sensor
    result = createAE(module);
    if (result == HTTP_CREATED) {
#ifdef DEBUG
      Serial.println("AE " + module + " created  !");
#endif

      // 2. Create a first container (CNT) to store the description(s) of the sensor
      result = createCNT(module, DESC_CNT_NAME);
      if (result == HTTP_CREATED) {
#ifdef DEBUG
        Serial.println("CNT " + module + "/" + DESC_CNT_NAME + " created  !");
#endif


        // Create a first description under this container in the form of a ContentInstance (CI)
        result = createCI(module, DESC_CNT_NAME, intialDescription);
        if (result == HTTP_CREATED) {
#ifdef DEBUG
          Serial.println("CI " + module + "/" + DESC_CNT_NAME + "/{initial_description} created !");
#endif
        }
      }

      // 3. Create a second container (CNT) to store the data  of the sensor
      result = createCNT(module, DATA_CNT_NAME);
      if (result == HTTP_CREATED) {
#ifdef DEBUG
        Serial.println("CNT " + module + "/" + DATA_CNT_NAME + " created !");
#endif

        // Create a first data value under this container in the form of a ContentInstance (CI)
        result = createCI(module, DATA_CNT_NAME, initialData);
        if (result == HTTP_CREATED) {
#ifdef DEBUG
          Serial.println("CI " + module + "/" + DATA_CNT_NAME + "/{initial_aata} created !");
#endif
        }
      }

      // 3. if the module is an actuator, create a third container (CNT) to store the received commands
      if (isActuator) {
        result = createCNT(module, CMND_CNT_NAME);
        if (result == HTTP_CREATED) {
#ifdef DEBUG
          Serial.println("CNT " + module + "/" + CMND_CNT_NAME + " created !");
#endif

          // subscribe to any ne command put in this container
          result = createSUB(module);
          if (result == HTTP_CREATED) {
#ifdef DEBUG
            Serial.println("SUB " + module + "/" + CMND_CNT_NAME + "/SUB_" + module + " created !");
#endif
          }
        }
      }
    }
  }
}


void init_WiFi() {
  Serial.println("Connecting to  " + String(WIFI_SSID) + " ...");
  WiFi.persistent(false);
  WiFi.begin(WIFI_SSID, WIFI_PSWD);

  // wait until the device is connected to the wifi network
  while (WiFi.status() != WL_CONNECTED) {
    delay(WIFI_DELAY);
    Serial.print(".");
  }

  // Connected, show the obtained ip address
  Serial.println("WiFi Connected ==> IP Address = " + WiFi.localIP().toString());
}

void init_HTTPServer() {
  server.begin();
  Serial.println("Local HTTP Server started !");
}

void task_HTTPServer() {
  // Check if a client is connected
  client = server.available();
  if (!client)
    return;

  // Wait until the client sends some data
  Serial.println("New client connected. Receiving request... ");
  while (!client.available()) {
#ifdef DEBUG_MODE
    Serial.print(".");
#endif
    delay(5);
  }

  // Read the request
  String request = client.readString();
  Serial.println(request);
  client.flush();



  int start, end;
  // identify the right module (sensor or actuator) that received the notification
  // the URL used is ip:port/ae
  start = request.indexOf("/");
  end = request.indexOf("HTTP") - 1;
  context = request.substring(start + 1, end);
#ifdef DEBUG
  Serial.println(String() + start + " , " + end + " -> " + context + ".");
#endif


  // ingore verification messages
  if (request.indexOf("vrq") > 0) {
    client.flush();
    return;
  }


  //Parse the request and identify the requested command from the device
  //Request should be like "[operation_name]"
  start = request.indexOf("[");
  end = request.indexOf("]"); // first occurence of
  command = request.substring(start + 1, end);
#ifdef DEBUG
  Serial.println(String() + start + " , " + end + " -> " + command + ".");
#endif

  client.flush();
}

// ######### START OF EXAMPLE ######### //
void init_luminosity() {
  String initialDescription = "Name = LuminositySensor\t"
                              "Unit = Lux\t"
                              "Location = Home\t";
  String initialData = "0";
  registerModule("LuminositySensor", false, initialDescription, initialData);
}

void task_luminosity() {
  int sensorValue;
  int sensorPin = A0;
  sensorValue = analogRead(sensorPin);
  //sensorValue = random(10, 20);
#ifdef DEBUG
  Serial.println("luminosity value = " + sensorValue);
#endif

  String ciContent = String(sensorValue);

  createCI("LuminositySensor", DATA_CNT_NAME, ciContent);
}


void init_led() {
  String initialDescription = "Name = LedActuator\t"
                              "Location = Home\t";
  String initialData = "off";
  registerModule("LedActuator", true, initialDescription, initialData);
}
//void task_led() {
//
//}
//
//void command_led(String cmd) {
//  //Serial.print(cmd);
//  if (cmd == "switchOn") {
//#ifdef DEBUG
//    Serial.println("Switching on the LED ...");
//#endif
//    digitalWrite(LED_PIN, LOW);
//  }
//  else if (cmd == "switchOff") {
//#ifdef DEBUG
//    Serial.println("Switching off the LED ...");
//#endif
//    digitalWrite(LED_PIN, HIGH);
//  }
//}
// ######### END OF EXAMPLE ######### //

/////////////////////////////////////////////////////////////////////////////////

// ######################################################## //
// ######### USE THIS SPACE TO DECLARE VARIABLES  ######### //
// ########################################################  //

float temp, hum;

// ########################################################  //
void dht_usr()
{  Serial.println("Reading DHT values");
  // Reading temperature or humidity takes about 250 milliseconds!
  // Sensor readings may also be up to 2 seconds 'old' (its a very slow sensor)
  float h = dht.readHumidity();
  // Read temperature as Celsius (the default)
  float t = dht.readTemperature();
  // Read temperature as Fahrenheit (isFahrenheit = true)
  float f = dht.readTemperature(true);

  // Check if any reads failed and exit early (to try again).
  if (isnan(h) || isnan(t) || isnan(f)) {
    ;//Serial.println(F("Failed to read from DHT sensor!"));
    ;
    return;
  }

  // Compute heat index in Fahrenheit (the default)
  float hif = dht.computeHeatIndex(f, h);
  // Compute heat index in Celsius (isFahreheit = false)
  float hic = dht.computeHeatIndex(t, h, false);
  dht_val[0] = h;
  dht_val[1] = t;
  ThingSpeak.setField(1, String(h));
  ThingSpeak.setField(2, String(t));

  // write to the ThingSpeak channel
  x = ThingSpeak.writeFields(myChannelNumber1, myWriteAPIKey1);
  if (x == 200) {
    Serial.println("Channel update successful.");
  }
  else {
    Serial.println("Problem updating channel. HTTP error code " + String(x));
  }
  Serial.print(F("Humidity: "));
  Serial.print(h);
  Serial.print(F("%  Temperature: "));
  Serial.print(t);
  Serial.print(F("°C "));
  Serial.print(f);
  Serial.print(F("°F  Heat index: "));
  Serial.print(hic);
  Serial.print(F("°C "));
  Serial.print(hif);
  Serial.println(F("°F"));
}
float sgp_val[10];
void sgp_usr()
{
  if (! sgp.IAQmeasure()) {
    Serial.println("Measurement failed");
    return;
  }
  sgp_val[0] = sgp.TVOC;
  sgp_val[1] = sgp.eCO2;
  Serial.print("TVOC "); Serial.print(sgp.TVOC); Serial.print(" ppb\t");
  Serial.print("eCO2 "); Serial.print(sgp.eCO2); Serial.println(" ppm");
  ThingSpeak.setField(1, String(sgp_val[0]));
  ThingSpeak.setField(2, String(sgp_val[1]));

  // write to the ThingSpeak channel
  int x = ThingSpeak.writeFields(myChannelNumber2, myWriteAPIKey2);
  if (x == 200) {
    Serial.println("Channel update successful.");
  }
  else {
    Serial.println("Problem updating channel. HTTP error code " + String(x));
  }
  if (! sgp.IAQmeasureRaw()) {
    Serial.println("Raw Measurement failed");
    return;
  }
  //  sgp_val[2]= sgp.rawH2;
  //  Serial.print("Raw H2 "); Serial.print(sgp.rawH2); Serial.print(" \t");
  //  Serial.print("Raw Ethanol "); Serial.print(sgp.rawEthanol); Serial.println("");

  delay(1000);


  uint16_t TVOC_base, eCO2_base;
  if (! sgp.getIAQBaseline(&eCO2_base, &TVOC_base)) {
    Serial.println("Failed to get baseline readings");
    return;
  }
  Serial.print("****Baseline values: eCO2: 0x"); Serial.print(eCO2_base, HEX);
  Serial.print(" & TVOC: 0x"); Serial.println(TVOC_base, HEX);


}

float mgs_val[3];
void mgs_usr()
{
  float c;

  c = gas.measure_NH3();
  mgs_val[0] = c;
  Serial.print("The concentration of NH3 is ");
  if (c >= 0) {
    Serial.print(c);
  }
  else Serial.print("invalid");
  Serial.println(" ppm");

  c = gas.measure_CO();
  mgs_val[1] = c;
  Serial.print("The concentration of CO is ");
  if (c >= 0) {
    Serial.print(c);

  }
  else Serial.print("invalid");
  Serial.println(" ppm");

  c = gas.measure_NO2();
  mgs_val[2] = c;
  Serial.print("The concentration of NO2 is ");
  if (c >= 0) {
    Serial.print(c);
  }
  else Serial.print("invalid");
  Serial.println(" ppm");
  ThingSpeak.setField(1, String(mgs_val[0]));
  ThingSpeak.setField(2, String(mgs_val[1]));
  ThingSpeak.setField(3, String(mgs_val[2]));
  // write to the ThingSpeak channel
  x = ThingSpeak.writeFields(myChannelNumber4, myWriteAPIKey4);
  if (x == 200) {
    Serial.println("Channel update successful.");
  }
  else {
    Serial.println("Problem updating channel. HTTP error code " + String(x));
  }
  //    c = gas.measure_C3H8();
  //    Serial.print("The concentration of C3H8 is ");
  //    if(c>=0) {
  //      Serial.print(c);
  //    }
  //    else Serial.print("invalid");
  //    Serial.println(" ppm");
  //
  //    c = gas.measure_C4H10();
  //    Serial.print("The concentration of C4H10 is ");
  //    if(c>=0) {
  //      Serial.print(c);
  //    }
  //    else Serial.print("invalid");
  //    Serial.println(" ppm");
  //
  //    c = gas.measure_CH4();
  //    Serial.print("The concentration of CH4 is ");
  //    if(c>=0) {
  //      Serial.print(c);
  //    }
  //    else Serial.print("invalid");
  //    Serial.println(" ppm");
  //
  //    c = gas.measure_H2();
  //    Serial.print("The concentration of H2 is ");
  //    if(c>=0) {
  //      Serial.print(c);
  //    }
  //    else Serial.print("invalid");
  //    Serial.println(" ppm");
  //
  //    c = gas.measure_C2H5OH();
  //    Serial.print("The concentration of C2H5OH is ");
  //    if(c>=0) {
  //      Serial.print(c);
  //    }
  //    else Serial.print("invalid");
  //    Serial.println(" ppm");

  delay(1000);
  ;//Serial.println("...");

}
float sds_val[10];
void sds_usr()
{
  Serial.println("sds");
  PmResult pm = sds.readPm();
  if (pm.isOk()) {
    Serial.print("PM2.5 = ");
    Serial.print(pm.pm25);
    Serial.print(", PM10 = ");
    Serial.println(pm.pm10);
    sds_val[0] = pm.pm25;
    sds_val[1] = pm.pm10;
    ThingSpeak.setField(1, String(pm.pm25));
    ThingSpeak.setField(2, String(pm.pm10));

    // write to the ThingSpeak channel
    x = ThingSpeak.writeFields(myChannelNumber3, myWriteAPIKey3);
    if (x == 200) {
      Serial.println("Channel update successful.");
    }
    else {
      Serial.println("Problem updating channel. HTTP error code " + String(x));
    }
  }
}
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
void loop() {
  // ############################################################### //
  // ######### USE THIS SPACE FOR YOUR SENSOR POLING CODE  ######### //
  // ###############################################################  //
  Serial.print("yo");
  for(int i=0;i<30;i++)
  { dht_usr();
    sgp_usr();
    mgs_usr();
    sds_usr();
    delay(20000);
  }
  // ######################################################### //




  // ################################################################### //
  // ######### USE THIS SPACE FOR YOUR SENDING DATA TO SERVER  ######### //
  // ################################################################### //

  /*
      CreateCI(AE_NAME,CONTAINER_NAME,SENSOR_VALUE)

      CreateCI is what posts your sensor data into the container.

      In the below example:
            AE_NAME: Team8_Automated_Driving (As stated in the resource tree)
            CONTAINER_NAME : node_1 ( or as stated in the resource tree)
            SENSOR_VALUE : string of comma separated all sensor values (Eg: 27,25 is temp,hum)
  */


  // Storing as a string in a single containers
  String sensor_value_string;
  sensor_value_string = String("dht : ") + String(dht_val[0]) + String(" , ") + String(dht_val[1]) + String(" \n ") + String("sgp : ") + String(sgp_val[0]) + String(" , ") + String(sgp_val[1]) + String(" \n ") + String("multi : ") + String(mgs_val[0]) + String(" , ") + String(mgs_val[1]) + String(" , ") + String(mgs_val[2]) + String(" \n ") + String("sds : ") + String(sds_val[0]) + String(" , ") + String(sds_val[1]) + String(" \n ") ;
  createCI("Team14_Indoor_air_pollution_Mess", "node_1", sensor_value_string);

  // Check if the data instance was created.
//  delay(600000); // DO NOT CHANGE THIS VALUE


  // ################################################################### //
}
